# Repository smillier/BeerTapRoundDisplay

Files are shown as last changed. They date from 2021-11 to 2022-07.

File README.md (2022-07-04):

# BeerTapRoundDisplay
Kegerator custom display using GC9A01 1.28" round display, hx711 with weight sensors and ESP32.
Project is fully working now for my needs. Lot of improvements are coming.
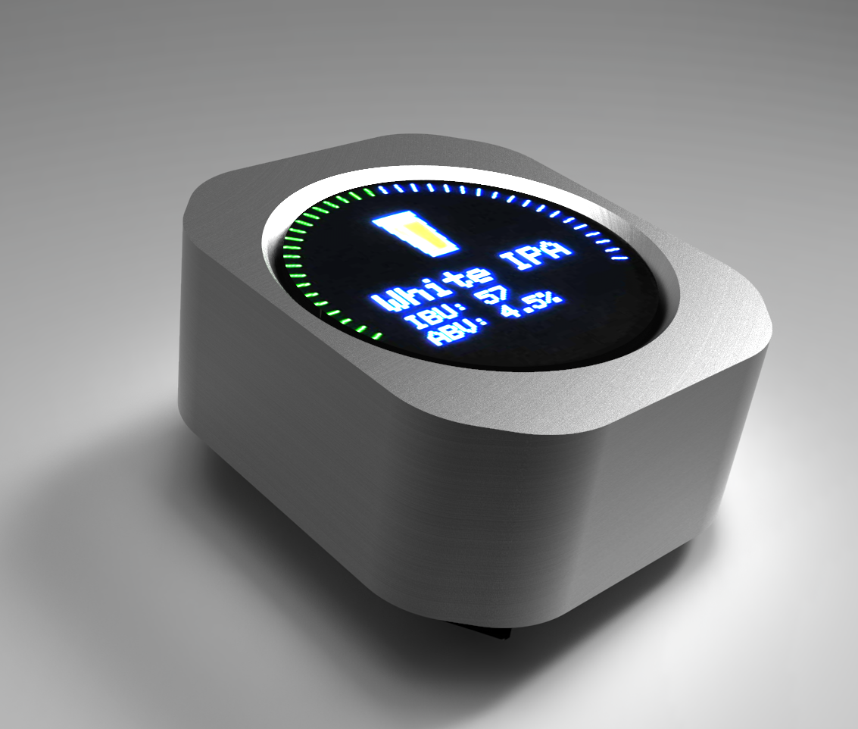
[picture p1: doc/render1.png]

## Hardware list

<table>
<thead>
	<tr>
		<th>Hardware</th>
		<th>Indic. price</th>
		<th>Link</th>
	</tr>
</thead>
<tbody>
	<tr>
		<td>ESP32 (Az-Delivery)</td>
		<td>11.99€</td>
		<td><a href="https://www.amazon.fr/gp/product/B071P98VTG/ref=ppx_yo_dt_b_search_asin_title?ie=UTF8&th=1" target ="blank">Amazon</a></td>
	</tr>
	<tr>
		<td>GC9A01 1.28" Oled Display</td>
		<td>5.93€</td>
		<td><a href="https://www.aliexpress.com/item/1005004296043855.html?spm=a2g0o.order_list.0.0.5a9f1802KPwI7w" target ="blank">AliExpress</a></td>
	</tr>
	<tr>
		<td>HX711 + Weight Sensors</td>
		<td>4.20€</td>
		<td><a href="https://www.aliexpress.com/item/1005002176327047.html?spm=a2g0o.order_list.0.0.22171802zh8MgL" target ="blank">AliExpress</a></td>
	</tr>
	<tr>
		<td>(Optionnal) 5V power supply</td>
		<td>15.67€</td>
		<td><a href="https://www.amazon.fr/LED-Alimentation-15W-MeanWell-LPV-20-5/dp/B00MWQEMXG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" target ="blank">Amazon</a><br>Could also be powered by ESP32 micro USB</td>
	</tr>
		<tr>
		<td>PCB</td>
		<td>To be defined</td>
		<td><a href="https://www.amazon.fr/LED-Alimentation-15W-MeanWell-LPV-20-5/dp/B00MWQEMXG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" target ="blank">OSHPark / PCBWay / JLCPCB</a></td>
	</tr>
</tbody>
</table>

## Flashing the ESP32
The ESP32 must first be flashed by USB. OTA is then available for future updates of the firmware.
1. Install VSCode
Follow the procedure here to download and install VSCode.
<a href="https://code.visualstudio.com/" target="_blank">https://code.visualstudio.com/</a>
2. Install PlatformIO extension 
Start VSCode and install the PlatformIO extension. See here:
https://platformio.org/install/ide?install=vscode
3. Download this repository
In a terminal use this command to clone this repo:
```dos
git clone https://github.com/smillier/BeerTapRoundDisplay.git
```

## Hardware schema and assembly
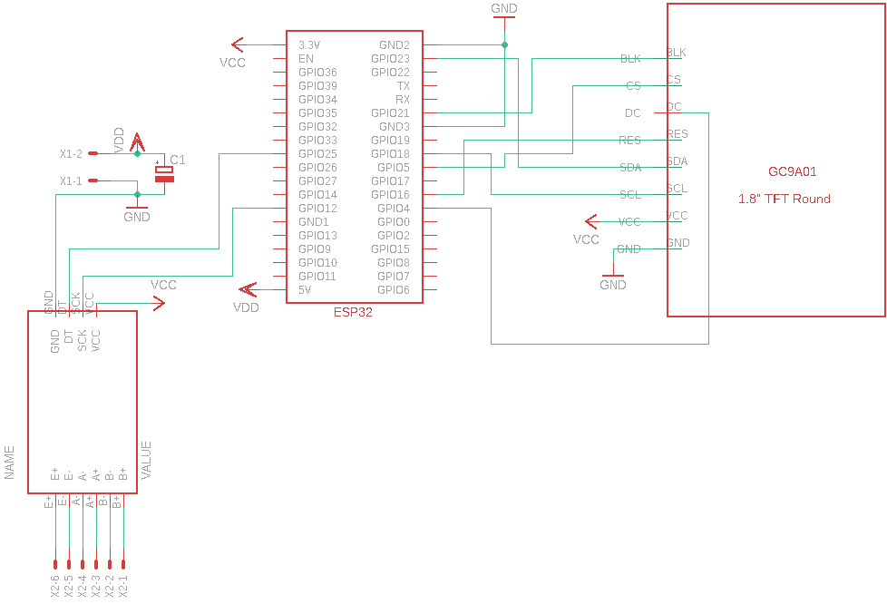
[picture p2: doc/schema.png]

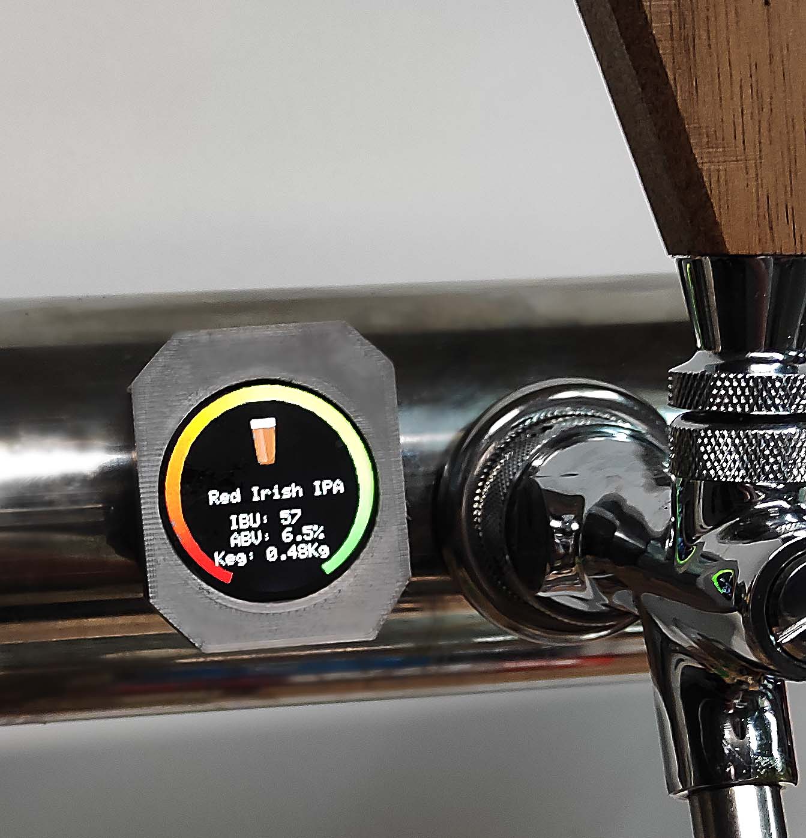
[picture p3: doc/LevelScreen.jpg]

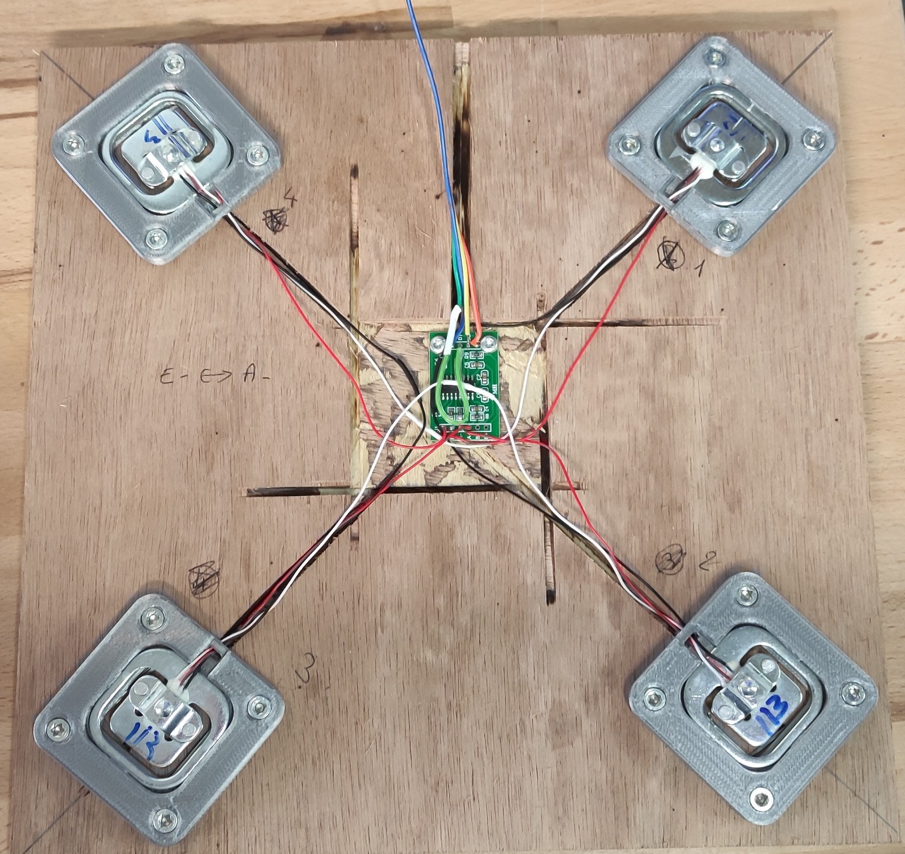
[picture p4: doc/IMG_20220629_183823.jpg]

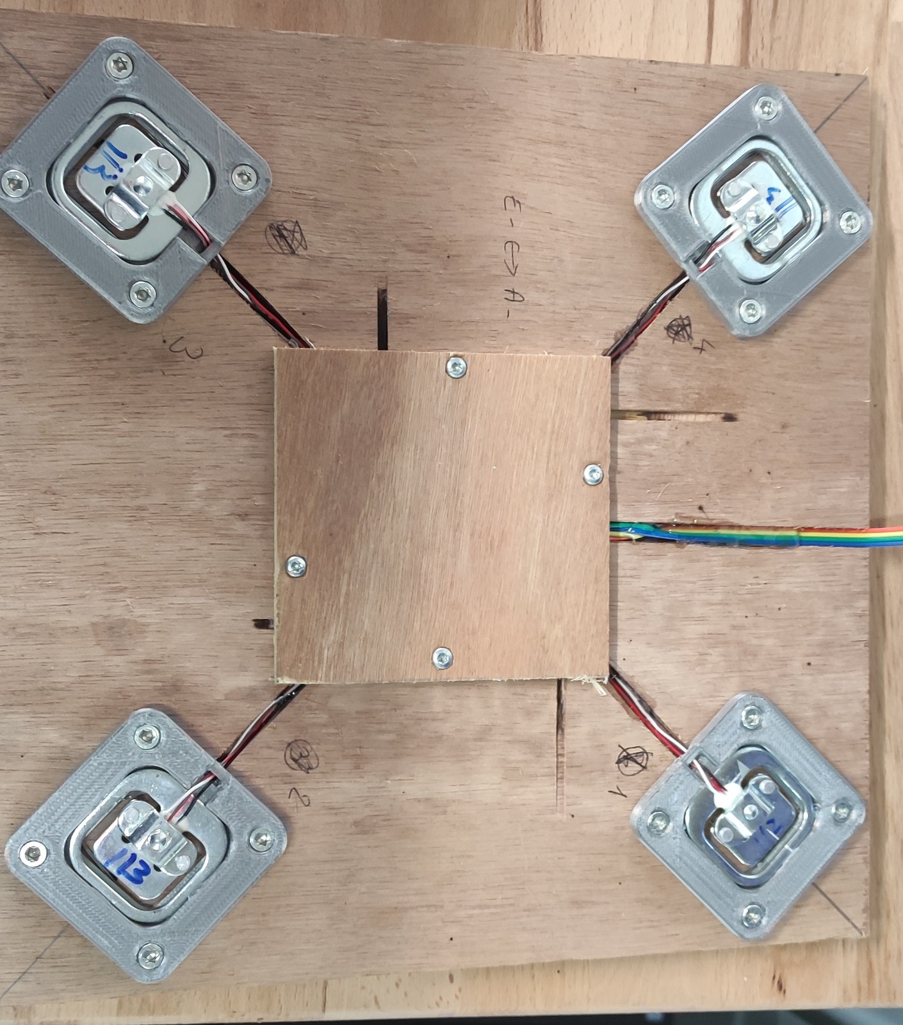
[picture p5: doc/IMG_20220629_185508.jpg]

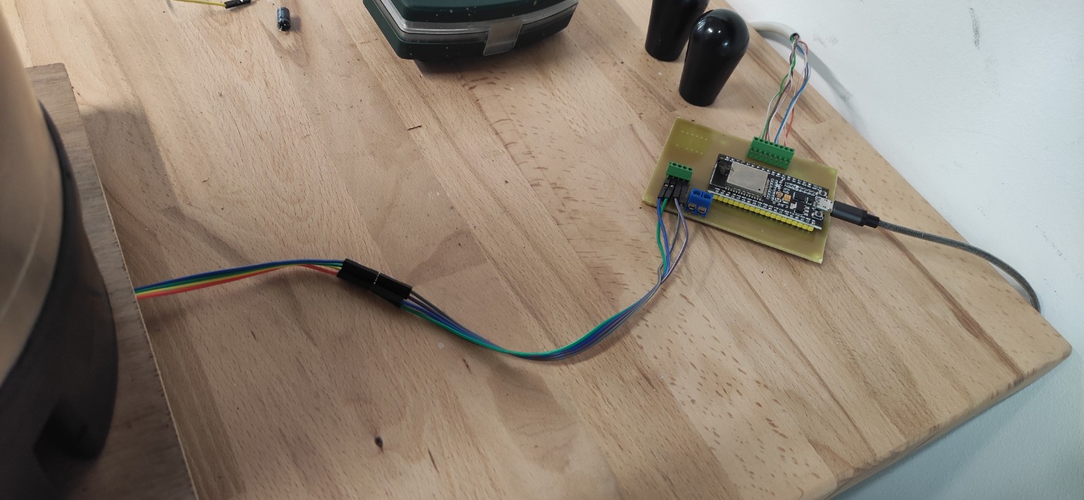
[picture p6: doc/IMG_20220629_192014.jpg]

display
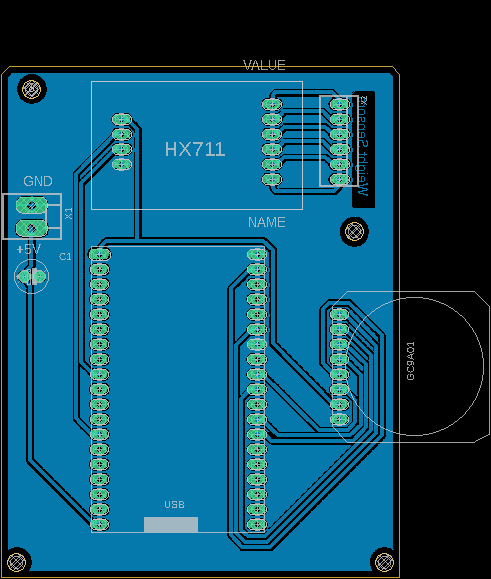
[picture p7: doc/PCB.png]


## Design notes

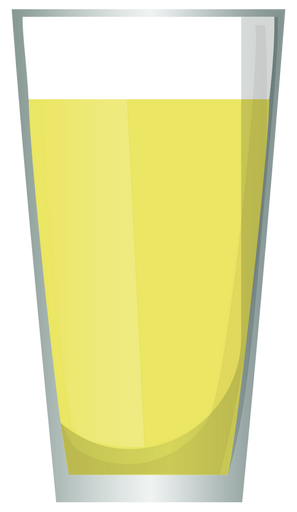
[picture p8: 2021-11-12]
doc/NSRM4.png

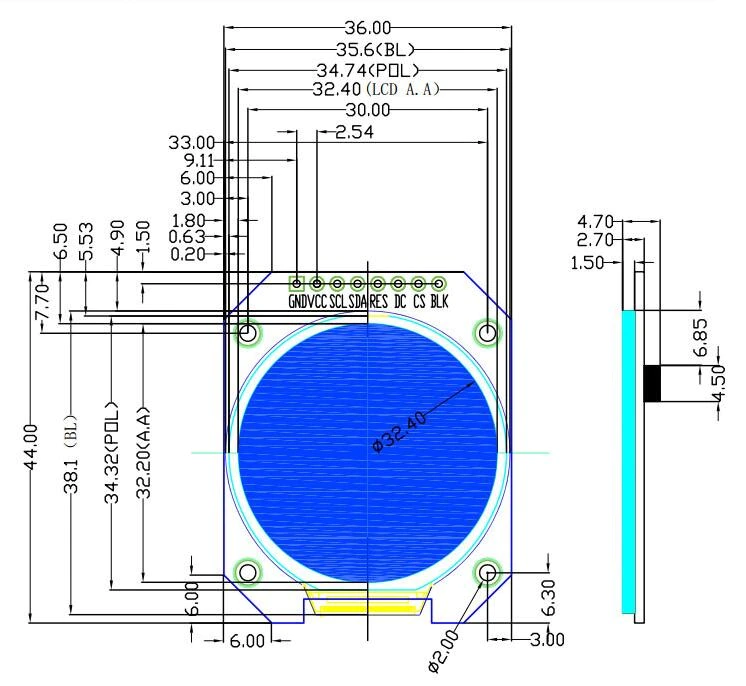
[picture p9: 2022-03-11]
Hec504144afb6410caa0c1e71d3824c3cw.webp

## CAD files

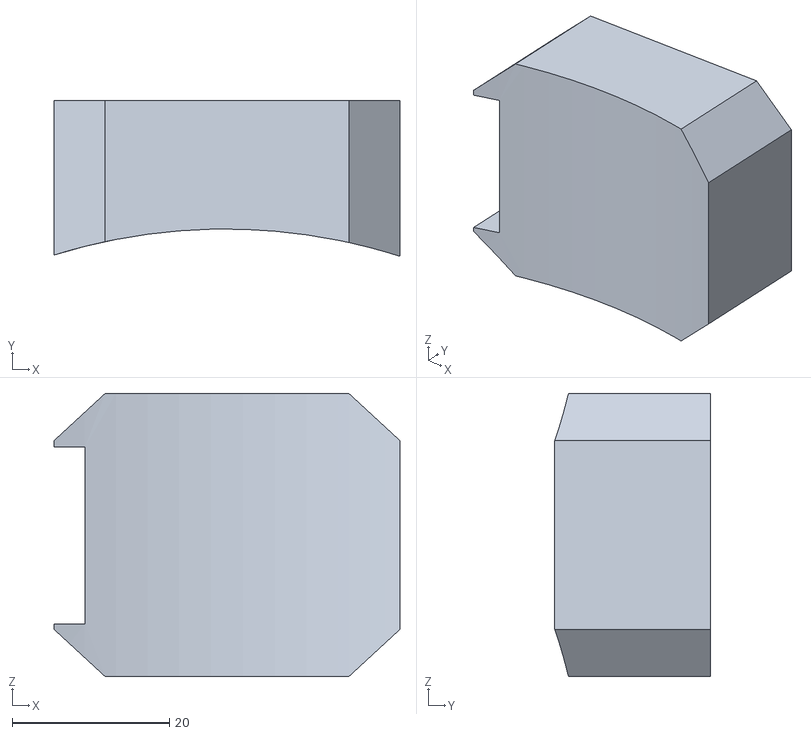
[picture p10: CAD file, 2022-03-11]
Case/Base.STL
44.0 x 19.8 x 36.0

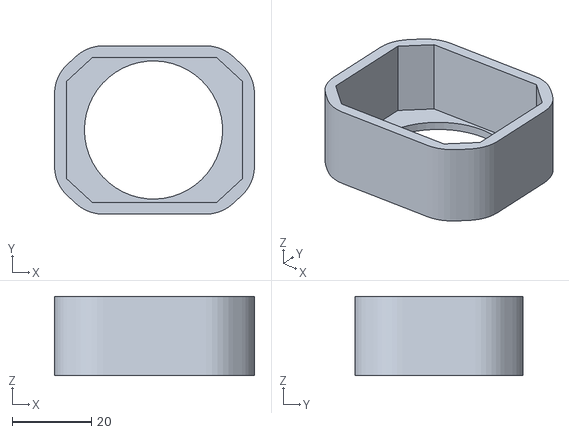
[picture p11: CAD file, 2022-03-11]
Case/ScreenBox.STL
50.5 x 42.5 x 20.0

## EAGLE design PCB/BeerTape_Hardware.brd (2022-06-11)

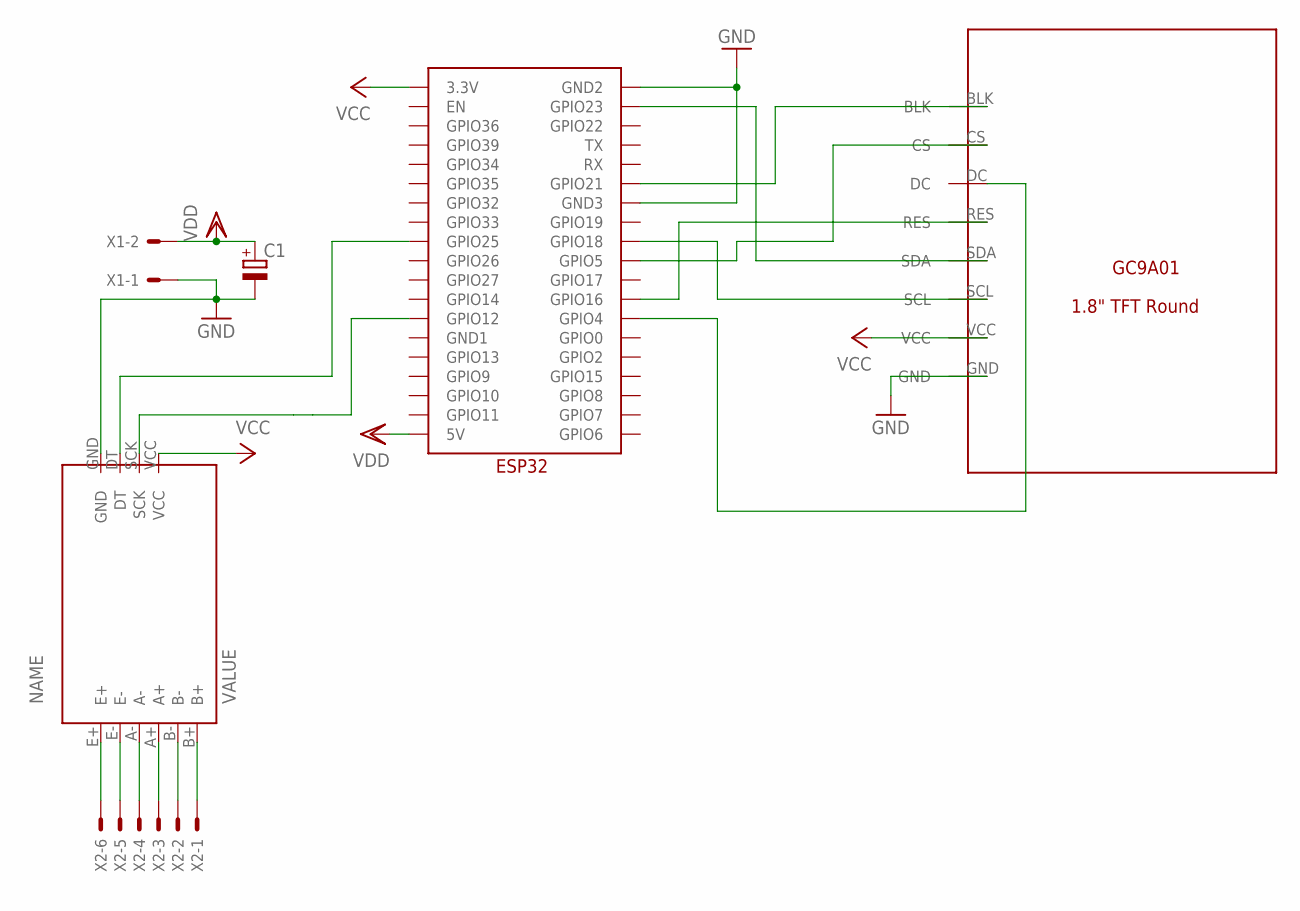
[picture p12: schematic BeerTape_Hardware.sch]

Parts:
C1: CPOL-EUE2,5-6E; E2,5-6E
HX711: HX711
U$1: GC9A01
U$2: ESP32
X1: KK-156-2
X2: 22-23-2061

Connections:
GND: C1.-, HX711.GND, U$1.GND, U$2.GND2, U$2.GND3, X1.1
unnamed: U$1.DC, U$2.GPIO4
unnamed: U$1.SDA, U$2.GPIO23
unnamed: U$1.BLK, U$2.GPIO21
unnamed: U$1.SCL, U$2.GPIO18
unnamed: U$1.RES, U$2.GPIO16
unnamed: U$1.CS, U$2.GPIO5
unnamed: HX711.SCK, U$2.GPIO12
unnamed: HX711.DT, U$2.GPIO25
unnamed: HX711.E+, X2.6
unnamed: HX711.E-, X2.5
unnamed: HX711.A-, X2.4
unnamed: HX711.A+, X2.3
unnamed: HX711.B-, X2.2
unnamed: HX711.B+, X2.1
VCC: HX711.VCC, U$1.VCC, U$2.3.3V
VDD: C1.+, U$2.5V, X1.2

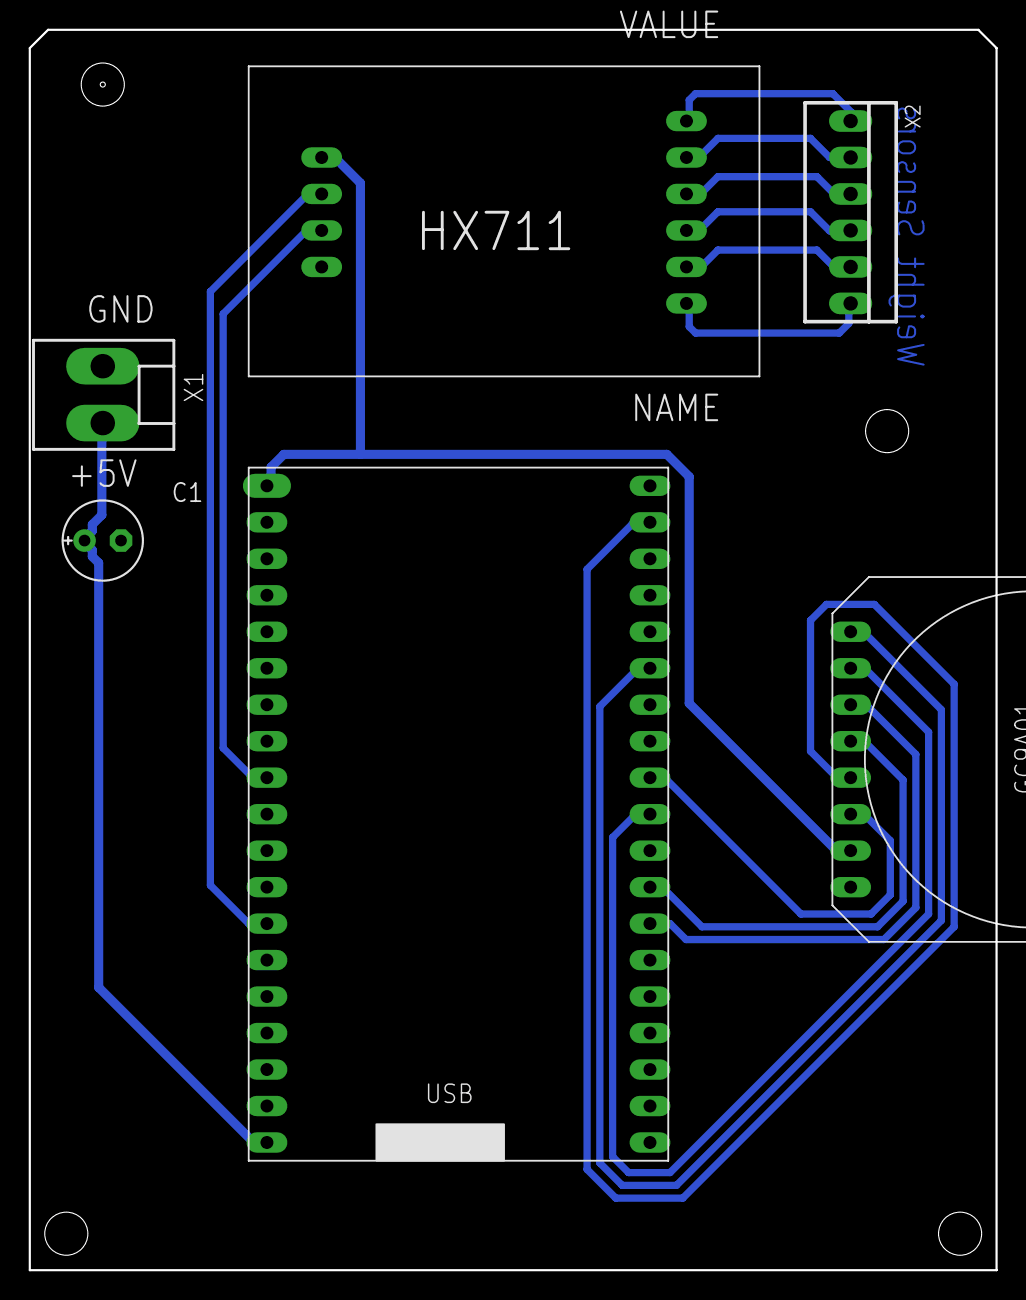
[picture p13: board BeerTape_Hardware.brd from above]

Board: 2 copper layers, 67.3 x 86.4 mm, 6 parts (0 on the bottom side), 17 nets.

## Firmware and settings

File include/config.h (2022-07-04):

#ifndef __CONFIG_H__
#define __CONFIG_H__

#include <String.h>
#include <WString.h>
#include "Preferences.h"
#include "ArduinoJson.h"

#define VERSION 0.1
#define DEBUG_MODE //Display debug messages in serial. Comment out to disable debug messages
#define TAPDISPLAY_BOARD 0.1

#define CFG_SSID_SIZE     32
#define CFG_PSK_SIZE      64
#define CFG_HOSTNAME_SIZE 16

//MQTT
 #define CFG_MQTT_PROTOCOL_SIZE     5
 #define CFG_MQTT_HOST_SIZE         32
  #define CFG_MQTT_USER_SIZE         32
  #define CFG_MQTT_PASSWORD_SIZE     32
  #define CFG_MQTT_DEFAULT_ACTIVATED false
  #define CFG_MQTT_DEFAULT_PROTOCOL  PSTR("mqtt")
  #define CFG_MQTT_DEFAULT_AUTH      false
  #define CFG_MQTT_DEFAULT_HOST      PSTR("mqtt.local")
  #define CFG_MQTT_DEFAULT_PORT      1883


#define DEFAULT_LED_BRIGHTNESS  50                // 50%

// Port pour l'OTA
#define DEFAULT_OTA_PORT     8266
#define DEFAULT_OTA_AUTH     PSTR("OTA_TapDisplay")
//#define DEFAULT_OTA_AUTH     ""


// Web Interface Configuration Form field names
#define CFG_FORM_SSID     PSTR("ssid")
#define CFG_FORM_PSK      PSTR("psk")
#define CFG_FORM_HOST     PSTR("host")
#define CFG_FORM_AP_PSK   PSTR("ap_psk")
#define CFG_FORM_OTA_AUTH PSTR("ota_auth")
#define CFG_FORM_OTA_PORT PSTR("ota_port")

//Colors for display
#define BACKGROUND BLACK
#define MARK_COLOR WHITE
#define SUBMARK_COLOR DARKGREY // LIGHTGREY
#define HOUR_COLOR WHITE
#define MINUTE_COLOR BLUE // LIGHTGREY
#define SECOND_COLOR RED
#define HOP_COLOR GREEN

#define SIXTIETH 0.016666667
#define TWELFTH 0.08333333
#define SIXTIETH_RADIAN 0.10471976
#define TWELFTH_RADIAN 0.52359878
#define RIGHT_ANGLE_RADIAN 1.5707963
#define RIGHT_STOP 5.4977 //7PI/4
#define LEFT_STOP 3.9 //5PI/4

//GC9A01 TFT pins:
#define TFT_BL 21
#define TFT_DC 4
#define TFT_CS 5
#define TFT_SCK 18
#define TFT_MOSI 23
#define TFT_MISO -1
#define TFT_RST 16

//HX711 pins:
#define HX711_dout 25 //mcu > HX711 dout pin
#define HX711_sck 12 //mcu > HX711 sck pin
#define SCALE_CALIBRATION_FACTOR 20710 //needs to be adapted to each scale

// Config saved into eeprom
// 1024 bytes total including CRC
typedef struct
{
  char ssid[CFG_SSID_SIZE+1];                       // SSID
  char psk[CFG_PSK_SIZE+1];                         // Pre shared key
  char host[CFG_HOSTNAME_SIZE+1];                   // Hostname
  char ap_psk[CFG_PSK_SIZE+1];                      // Access Point Pre shared key
  char ota_auth[CFG_PSK_SIZE+1];                    // OTA Authentication password
  uint32_t config;                                  // Bit field register
  uint16_t ota_port;                                // OTA port
  uint8_t  led_bright;                              // RGB Led brightness 0-255
  uint16_t oled_type;                               // Display OLED type (1306 or 1106)
  uint8_t  filler[104];                             // in case adding data in config avoiding loosing current conf by bad crc
  #ifdef MOD_EMONCMS
  _emoncms emoncms;                                 // Emoncms configuration
  #else
  uint8_t  filler_emoncms[128];
  #endif
  #ifdef MOD_JEEDOM
  _jeedom  jeedom;                                  // jeedom configuration
  #else
  uint8_t  filler_jeedom[256];
  #endif
  #ifdef MOD_MQTT
    _mqtt    mqtt;                                  // MQTT configuration
  #else
    uint8_t  filler_mqtt[128];
  #endif
  uint8_t  filler1[128];                            //Another filler in case we need more
  uint16_t crc;
} _Config;


// Exported variables/object instancied in main sketch
// ===================================================
extern _Config config;



// Declared exported function from route.cpp
// ===================================================
bool readConfig(bool clear_on_error=true);
bool saveConfig(void);
void resetConfig(void);
void showConfig(void);

extern unsigned long uptime;

extern String getBeerName();
extern void setBeerName(String value);

extern float getBeerSg();
extern void setBeerSg(float value);

extern int getBeerIBU();
extern void setBeerIBU(int value);

extern int getBeerEBC();
extern void setBeerEBC(int value);

extern float getBeerABV();
extern void setBeerABV(float value);

extern String getFileForEBC();
#endif

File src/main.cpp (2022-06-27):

/****************************************************************
 *  BeerTap Round Display
 *  https://github.com/smillier/BeerTapRoundDisplay
 *  Version: 0.1
*****************************************************************/
#include "config.h"
#include "setup.h"
#include "weightmeasure.h"
#include "FS.h"
#include "display.h"
#include <string>
#include <SPIFFS.h>
#include <ArduinoOTA.h>
#include "Preferences.h"

//Preferences preference;


void setup(void)
{
    //Serial.begin(115200);
    
    initialize();
    initWebServer();
}

void loop()
{
   // Serial.println(Config.beer_name);
    refresh_display();
    //redraw_hands_cached_draw_and_erase();
   delayMicroseconds(2000000); //2000000
    ArduinoOTA.handle();    
}

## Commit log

2022-02-24 Add Case stl for 3D printer
    [Base.STL, ScreenBox.STL]
2022-02-24 Add Hx711 Sensors
2022-03-01 Add Autodesk Eagle PCB files
    [BeerTape_Hardware.brd, BeerTape_Hardware.sch]
2022-03-01 Add PCB picture
2022-06-11 PCB tested OK
    [BeerTape_Hardware.brd, BeerTape_Hardware.sch]
2022-06-11 Add PCB images
2022-06-23 Code corrections for first tests
    [display.cpp, main.cpp, setup.cpp]
2026-07-04 Split balance (HX711) and display onto two boards linked over BLE
    The scale (ESP32-C6 + HX711 + weight sensors) is now a standalone
    BLE GATT server that can sit under the keg, while the round GC9A01
    display (still Wifi/OTA/webserver-capable) becomes a BLE client that
    reads the weight remotely instead of driving a local HX711.
    - scale-esp32c6/: new firmware, HX711 -> BLE notify, tare over BLE
    - display-esp32/: BLE client replaces the local HX711 wiring, adds a
    connection-status dot on screen and /tare, /scale_status endpoints
    - Verified both firmwares build with PlatformIO; updated several
    dependencies that no longer resolve in the registry (ElegantOTA,
    esp32async ESPAsyncWebServer/Asy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
2026-07-06 Revise README for project updates and clarifications
    Updated README to reflect changes in project description, board separation, and BLE protocol details.
2026-07-06 Port display-esp32 to ESP32-C3 + round GC9A01 touch display
    Switches the display board target from a bare ESP32 wired to a GC9A01
    breakout to an all-in-one ESP32-C3 + 1.28" round GC9A01 touch module
    (JCZN ESP32-2424S012 PCB). Adds CST816 touch support (tap to tare) and
    updates pin mapping, SPI bus setup, and PlatformIO board/env config
    accordingly.
2026-07-10 Fix display-esp32 boot on real ESP32-C3 hardware
    Hardware-tested on the JCZN ESP32-2424S012 board and fixes three bugs
    that only surfaced on real hardware:
    - MDNS.begin() was called before connectWifi(), so it failed and hung
    forever on first boot (no saved WiFi creds) before WiFi, the captive
    portal, or the display ever got a chance to run. Reordered.
    - SPIFFS partition (448KB) was too small for the data/ folder once
    filesystem overhead is accounted for, so SPIFFS.begin() failed and
    initialize() returned before ever calling display_init() - screen
    stayed blank. Trimmed both OTA app partitions (which had spare
    headroom) to grow SPIFFS to 704KB.
    - Pinned GFX Library for Arduino t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
2026-07-10 Fix scale-esp32c6 boot on real ESP32-C6 hardware, verify BLE end to end
    Hardware-tested BLE pairing and tare round-trip between the two real
    boards (scale connects, display shows green status, tap-to-tare logs
    "Tare requested by display" on the scale) and found two more bugs that
    only surfaced on real hardware:
    - scale_setup()/scale_tare()/getWeight() called the HX711 library's
    plain tare()/get_units(), which block forever if the HX711 never
    pulls DOUT low (e.g. load cells not wired yet) - this hung setup()
    before BLE ever started advertising. Switched to
    HX711::wait_ready_timeout() (1s) so a disconnected load cell degrades
    to reporting 0.0 instead of hanging the whole node.
    - Add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
2026-07-10 Replace jQuery/w3.css web UI with "BeeTap Control" design
    Implements the "BeeTap Control" Claude Design mockup (project
    e4750120-6cf9-463d-8540-04c588b6e35e) as a real, from-scratch web
    control panel for display-esp32, wired to the actual firmware API
    instead of the mockup's fake demo state. Dark/OLED theme, system fonts
    only (no CDN dependency, self-contained like the rest of the device).
    - New data/index.html, style.css, app.js: live weight + circular level
    gauge, tare, beer profile form, Wifi/firmware-OTA/system settings,
    toast notifications
    - Removes jquery-3.4.1.min.js/w3.css/script.js/param.xml (~330KB of
    the old ~376KB data/ folder was jQuery alone) - hardware-verified the
    ne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
2026-11-08 Require authentication on every display-esp32 endpoint
    A penetration test of the BeeTap Control web UI and API found that every
    endpoint had no authentication of any kind, including the custom
    beer-profile/tare/restart/reset_wifi API and - most seriously - the OTA
    firmware-upload path (ElegantOTA's /update, /ota/start, /ota/upload) and the
    separate ArduinoOTA WiFi-upload protocol. Anyone on the same network could
    silently reconfigure the device, reboot it, wipe its WiFi settings, or push
    arbitrary firmware with zero credentials.
    Fix:
    - checkAuth() (setup.cpp) gates every custom route behind HTTP Basic auth;
    ElegantOTA.begin() and ArduinoOTA.setPassword() now use the same credential
    for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
2026-11-08 Improve README readability: SVG architecture diagram, fenced code blocks
    - Replace the raw ASCII box-drawing diagram (unfenced, so it rendered
    broken/misaligned on GitHub - box-drawing characters only line up in a
    monospace font) with doc/architecture.svg: a proper vector diagram that
    stays crisp and legible at any screen size, with a prefers-color-scheme
    media query so it adapts to light/dark viewers.
    - Fence the "Repo structure" folder listing and the "Flashing both
    boards" shell commands in code blocks - both were plain paragraph
    text before, with no monospace alignment or syntax highlighting.
    - Simplify two heading titles ("scale-esp32c6/ - HX711 wiring" ->
    "scale-esp32c6: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
